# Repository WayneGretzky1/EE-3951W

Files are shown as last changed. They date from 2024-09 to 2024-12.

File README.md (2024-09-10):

# Strain guage

You will be designing and building a weight scale using a pre-built strain gauge bridge as shown in the link below:

Note that this package comes with a circuit board containing a custom load cell amplifier and 24 bit analog to digital converter (ADC). You will NOT be allowed to use this for your project. Instead, you will be reading the strain gauge output with the 10-bit ADC available on the Microchip PIC24FJ64GA002 microcontroller and the weight displayed on an appropriate LCD display. 

_**Detailed Specifications:**_

The system should display the weight of a test weight, in grams, to the nearest gram. The range should be 0-1000 grams. The system should have an auto zero ("tare") button to correct for any offset error. Note that a 10-bit ADC only has 1024 quantization levels so the system cannot correct large offset errors by digital offsets. Power supplies may be batteries, USB power, or wall power - it's your choice. The final system should function independently (not be tethered to a laptop other than possibly for power). More details will be provided in class.

_**The Boring Stuff:**_

1. Since the analog portion of the circuit will be connected to the analog to digital converter on your PIC board, putting the analog circuit in a box is not necessary, but you should plan on having it mounted in a stable fashion to facilitate testing and demonstration, If you do choose to put the circuit in a box, we suggest the  Bud 750-1015 box or equivalent, available from the ECE Depot, but other creative solutions are fine too including 3D printed boxes (there seems to be a competition every semester for who can make the cutest box); that's fine, but don't obsess too much about the box. The whole thing should be reasonable sized (6” on a side or less), if you feel you need to make a bigger board/box, please consult your TA first.

2. Components should be available from Digi-Key (they have the quickest delivery), Mouser Electronics (they are not quite as quick to ship as Digi-Key), or standard items from the ECE Depot. These parts will be ordered through the ECE Depot. A single IC containing the entire project is not permitted. If you wish to incorporate other parts from other suppliers you will be responsible for ordering and paying for them – we will not reimburse groups for these out of pocket expenses.

3. Instructions for Ordering Parts From the ECE Depot  Download Instructions for Ordering Parts From the ECE Depot(These instructions are from Fall 2023 but are still correct).

NOTE: not all parts listed in the supplier catalog are in stock, and ordering out of stock parts may result in substantial delays. Many parts are also surface mount – surface mount parts are often quite small and difficult to solder – if leaded parts (packages with leads like the ones you can plug into a proto-board) are available, they are usually the best choice. We have soldering facilities available in Anderson Labs, the ECE Depot (during the hours the Depot is open), and in the EXCEED lab.

Please designate ONE PERSON form your group to do all of the interfacing with the ECE Depot.

4. The total cost of all parts ordered through the ECE depot should not exceed $50. The circuit board, thermocouple wire, and thermocouple connectors do not need to be included in your budget.

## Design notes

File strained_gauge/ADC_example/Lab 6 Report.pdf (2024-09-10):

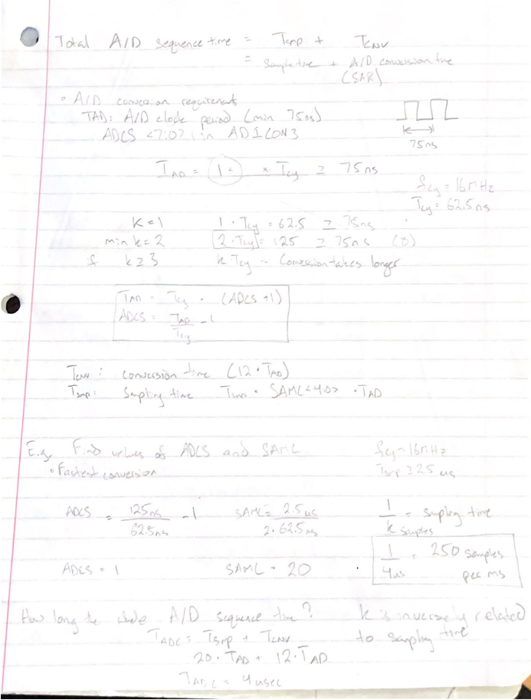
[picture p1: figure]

Max sampling rate is 250 samples per ms, in a sampling time of 4 us, these properties are inversely proportional in that the increase in sampling time (an increase in k) will lead to an decrease in sampling rate and vice versa. When our sample rate increases, we are able to paint a more accurate picture on our display since we are collecting precise values.

Main

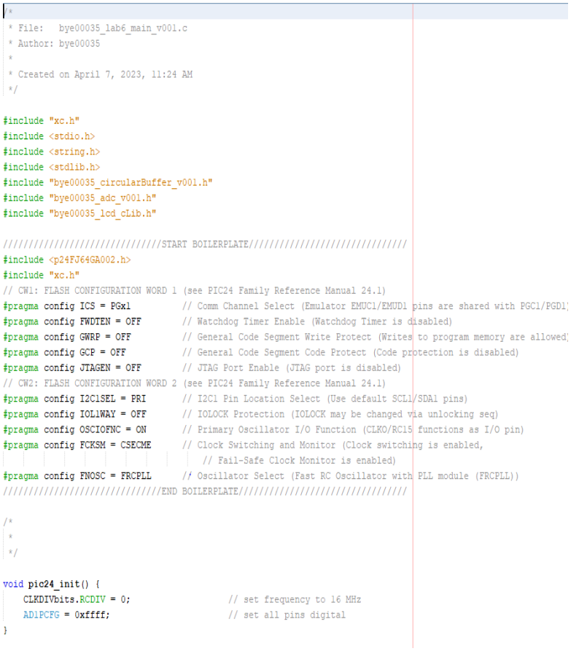
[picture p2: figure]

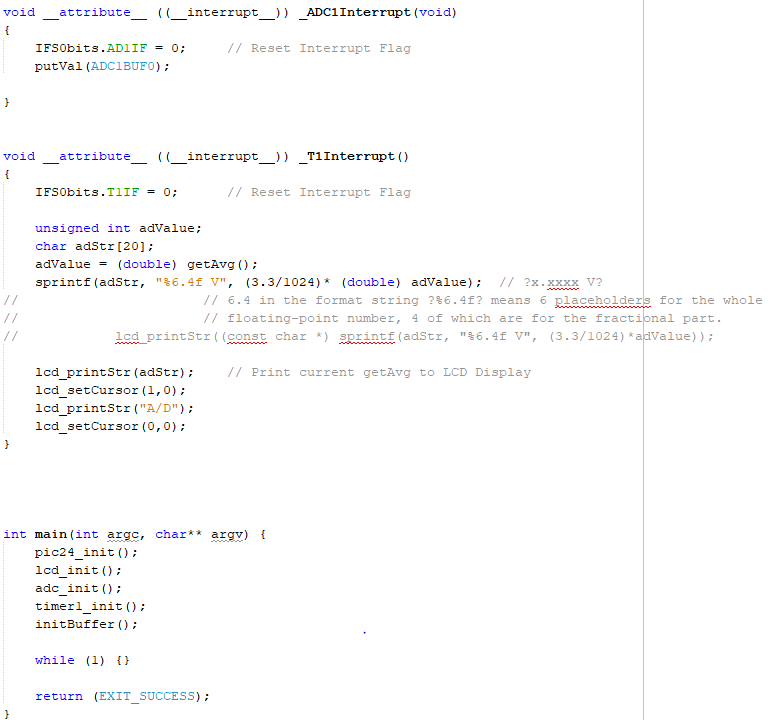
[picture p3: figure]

Header File

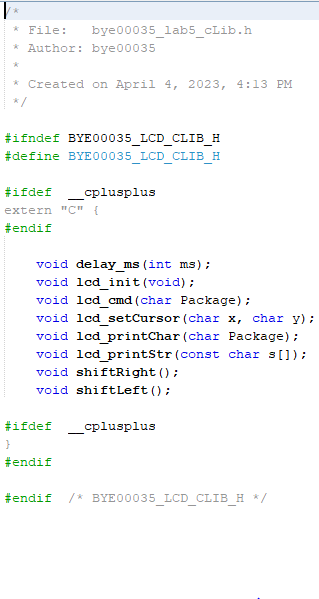
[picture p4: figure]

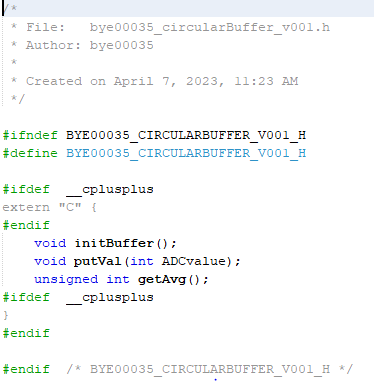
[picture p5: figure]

Library File

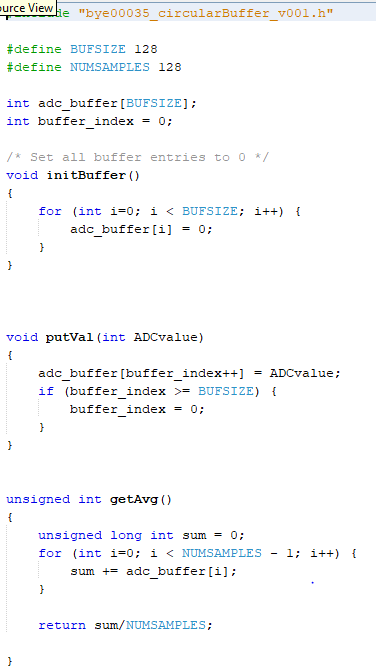
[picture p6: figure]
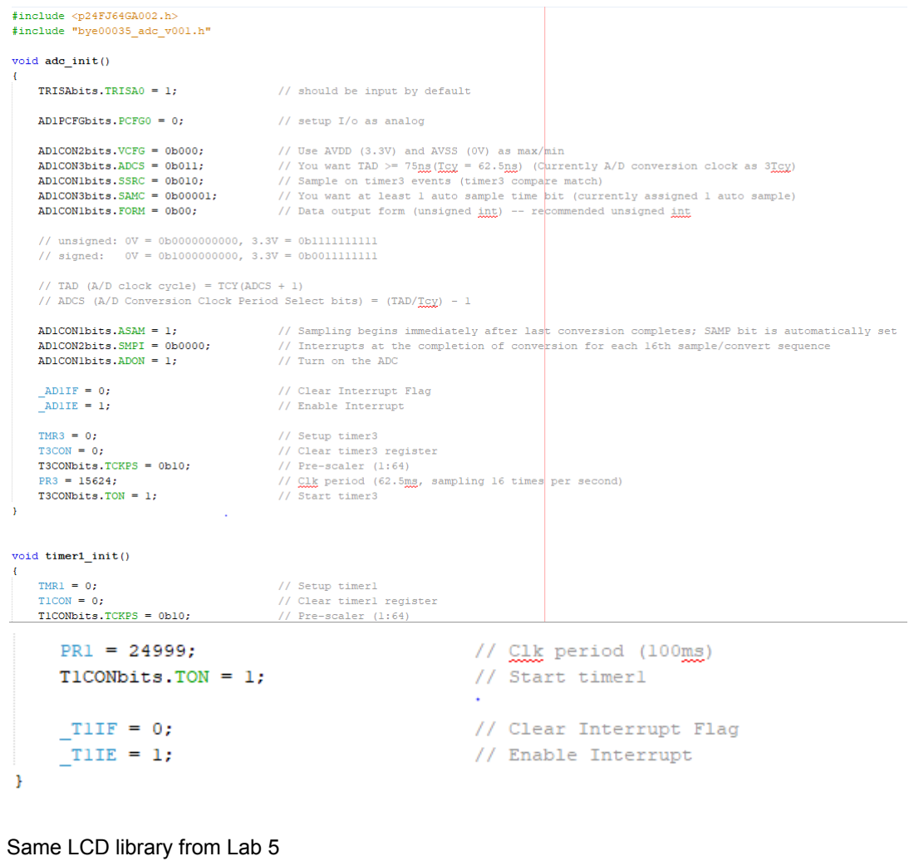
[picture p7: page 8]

Same LCD library from Lab 5

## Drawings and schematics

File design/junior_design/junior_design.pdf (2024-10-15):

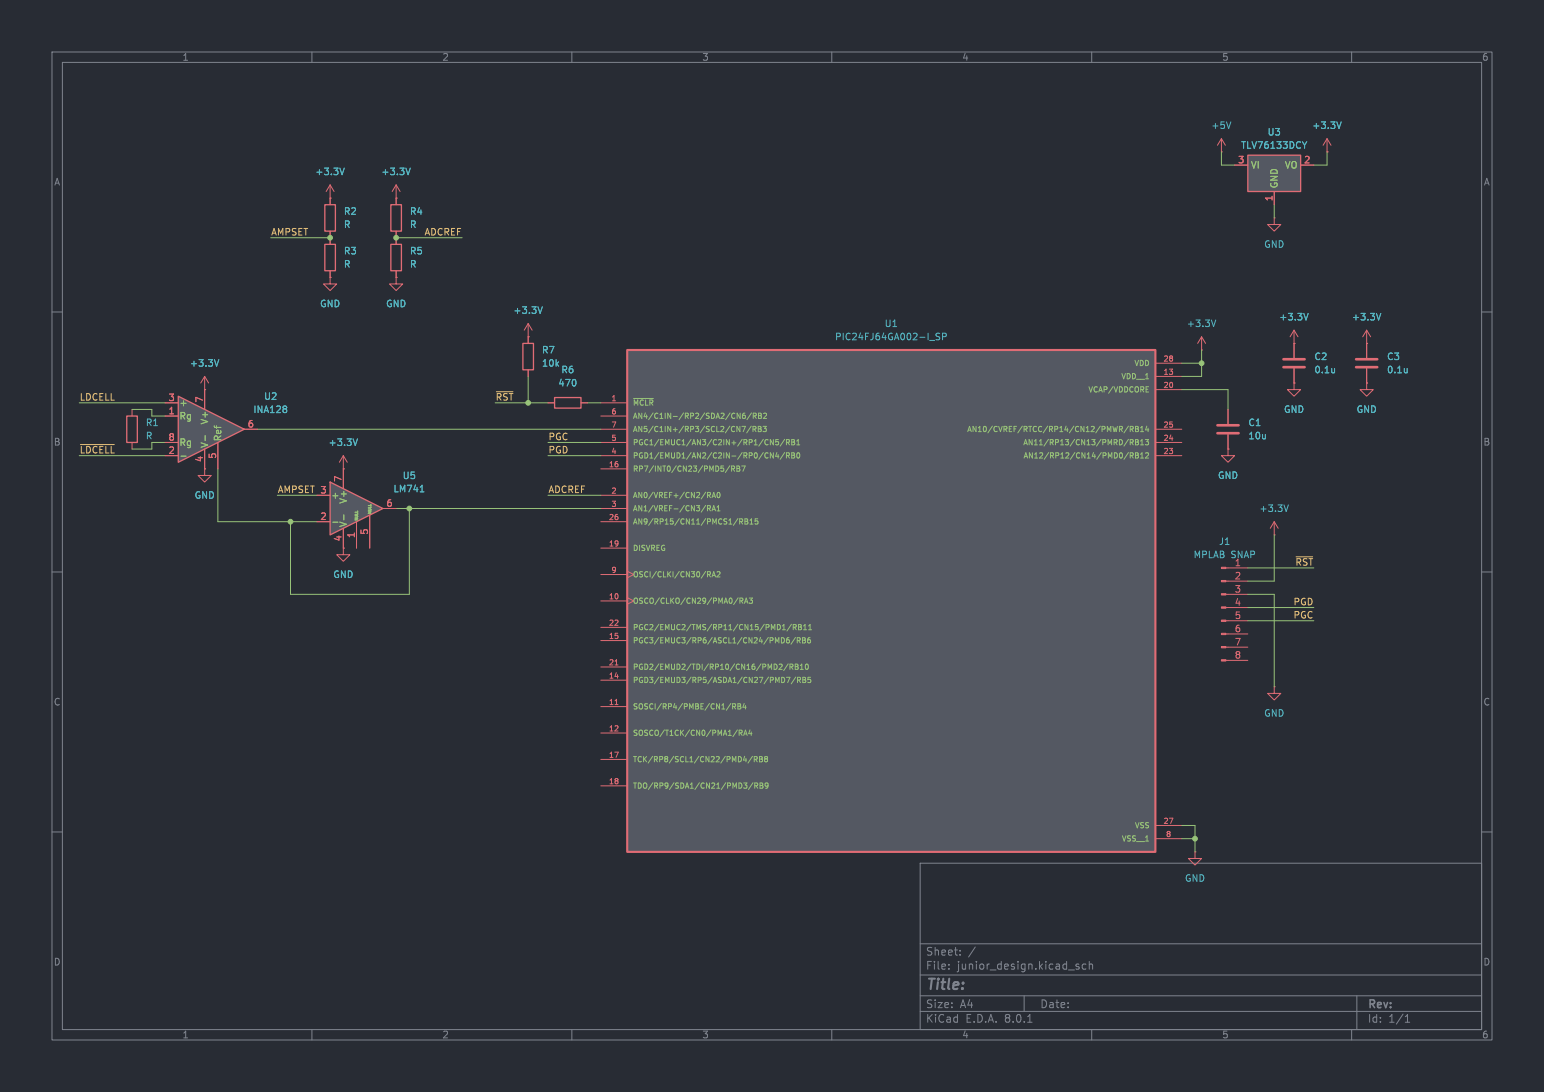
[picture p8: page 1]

Id: 1/1 Title: File: junior_design.kicad_sch Sheet: /

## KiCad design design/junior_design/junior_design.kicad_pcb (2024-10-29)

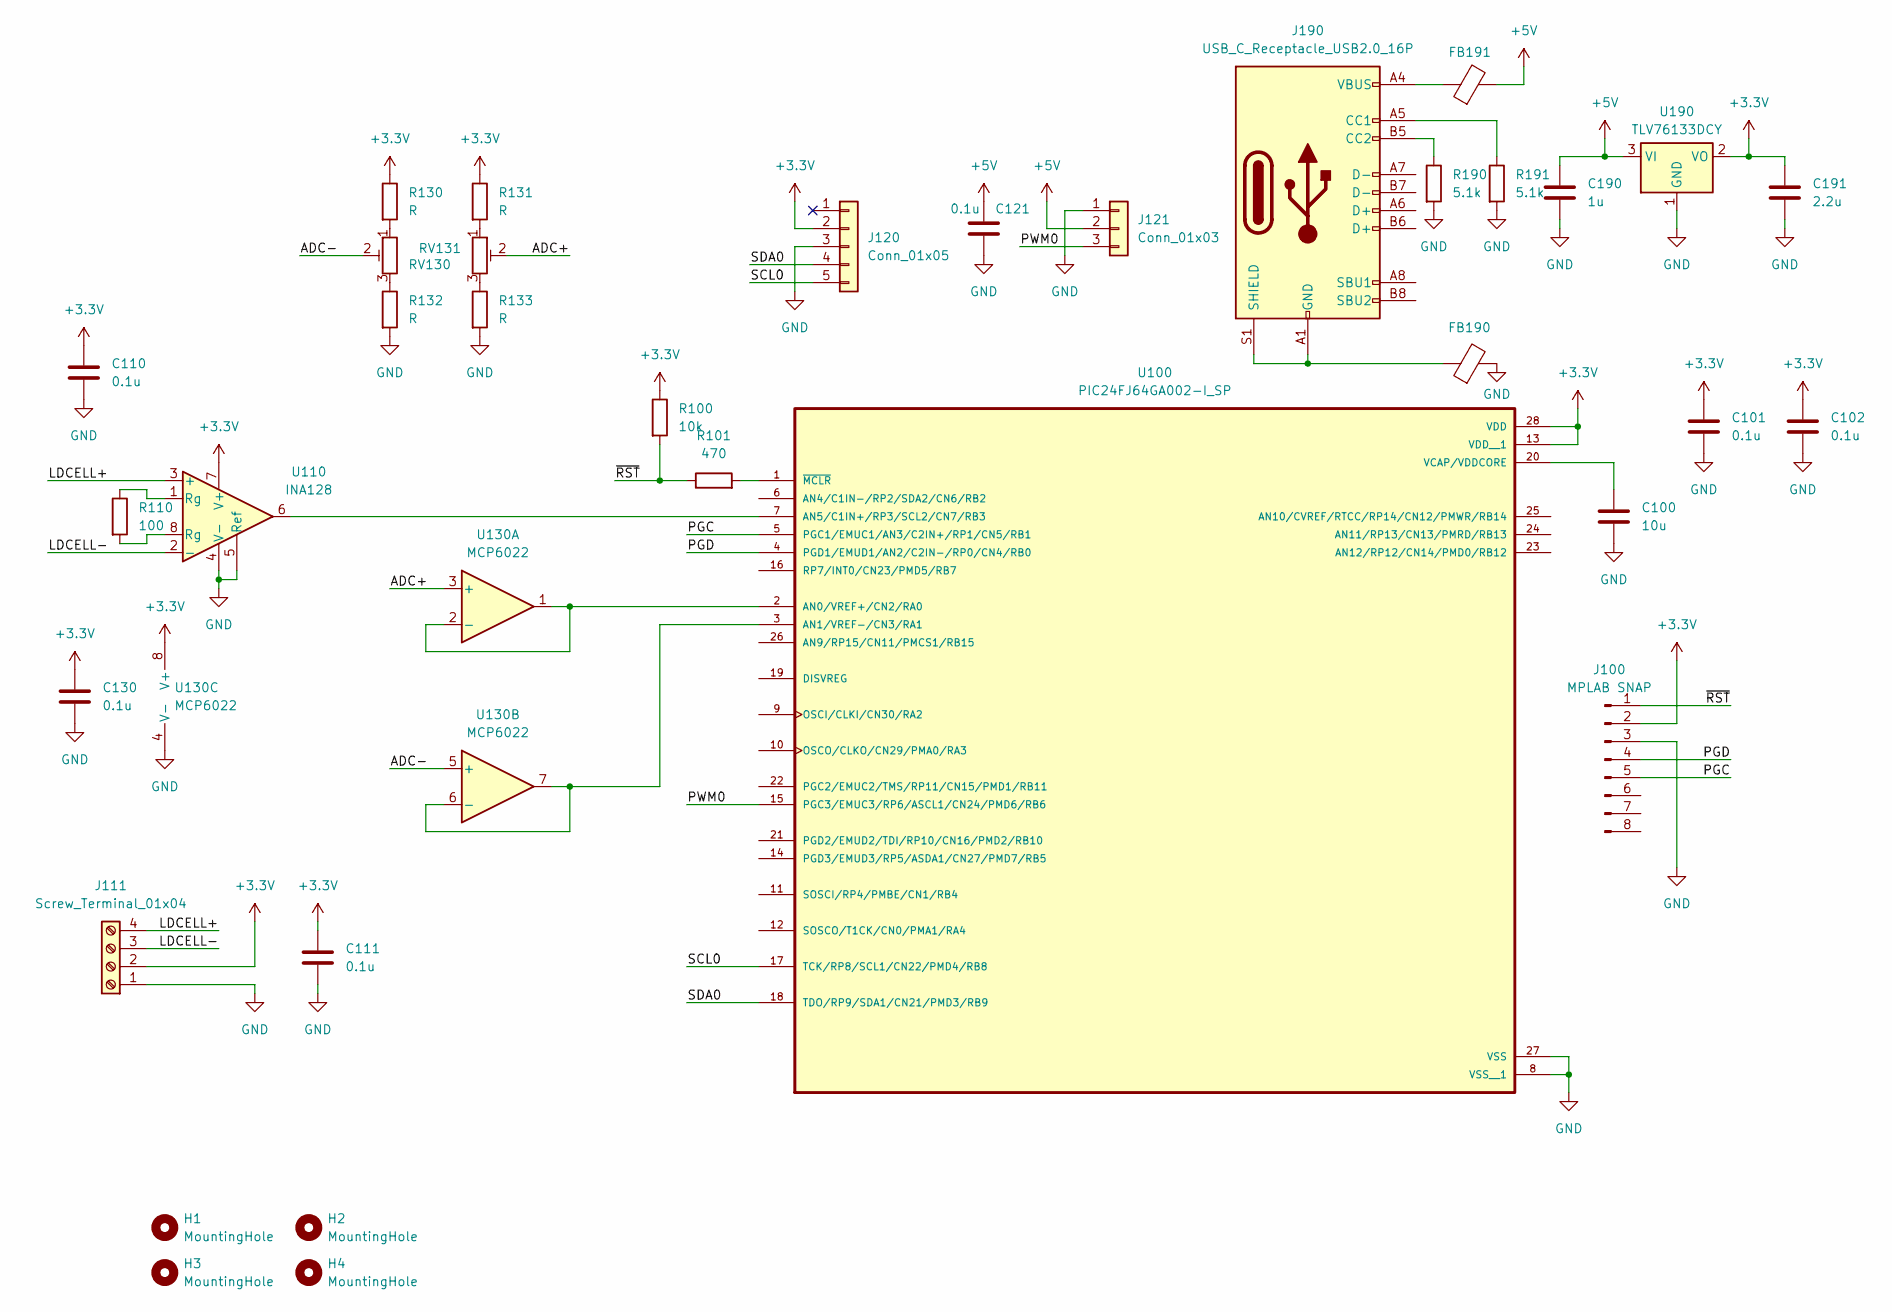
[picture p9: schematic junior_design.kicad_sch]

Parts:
C100: 10u; C_0805_2012Metric_Pad1.18x1.45mm_HandSolder
C101, C102, C110, C111, C121, C130: 0.1u; C_0603_1608Metric_Pad1.08x0.95mm_HandSolder
C190: 1u; C_0603_1608Metric_Pad1.08x0.95mm_HandSolder
C191: 2.2u; C_0603_1608Metric_Pad1.08x0.95mm_HandSolder
FB190, FB191: FerriteBead; L_0603_1608Metric_Pad1.05x0.95mm_HandSolder
H1, H2, H3, H4: MountingHole; MountingHole_2.7mm
J100: MPLAB SNAP; PinHeader_1x08_P2.54mm_Horizontal
J111: Screw_Terminal_01x04; PhoenixContact_MC_1,5_4-G-3.81_1x04_P3.81mm_Horizontal
J120: Conn_01x05; PinHeader_1x05_P2.54mm_Vertical
J121: Conn_01x03; PinHeader_1x03_P2.54mm_Vertical
J190: USB_C_Receptacle_USB2.0_16P; USB_C_Receptacle_GCT_USB4085
R100: 10k; R_0603_1608Metric_Pad0.98x0.95mm_HandSolder
R101: 470; R_0603_1608Metric_Pad0.98x0.95mm_HandSolder
R110: 100; R_0603_1608Metric_Pad0.98x0.95mm_HandSolder
R130, R131, R132, R133: R; R_0603_1608Metric_Pad0.98x0.95mm_HandSolder
R190, R191: 5.1k; R_0603_1608Metric_Pad0.98x0.95mm_HandSolder
RV130, RV131: R_Potentiometer_Trim; Potentiometer_Bourns_3266Y_Vertical
U100: PIC24FJ64GA002-I_SP; DIP-28_W7.62mm
U110: INA128; DIP-8_W7.62mm
U130: MCP6022; DIP-8_W7.62mm
U190: TLV76133DCY; SOT-223-3_TabPin2

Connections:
+3.3V: C101.1, C102.1, C110.1, C111.1, C130.1, C191.1, J100.2, J111.2, J120.2, R100.1, R130.1, R131.1, U100.13 (VDD__1), U100.28 (VDD), U110.7 (V+), U130.8 (V+), U190.2 (VO)
+5V: C121.1, C190.1, FB191.2, J121.2, U190.3 (VI)
/ADC+: RV131.2, U130.3 (+)
/ADC-: RV130.2, U130.5 (+)
/LDCELL+: J111.4, U110.3 (+)
/LDCELL-: J111.3, U110.2 (-)
/PGC: J100.5, U100.5 (PGC1/EMUC1/AN3/C2IN+/RP1/CN5/RB1)
/PGD: J100.4, U100.4 (PGD1/EMUD1/AN2/C2IN-/RP0/CN4/RB0)
/PWM0: J121.3, U100.15 (PGC3/EMUC3/RP6/ASCL1/CN24/PMD6/RB6)
/SCL0: J120.5, U100.17 (TCK/RP8/SCL1/CN22/PMD4/RB8)
/SDA0: J120.4, U100.18 (TDO/RP9/SDA1/CN21/PMD3/RB9)
/~RST: J100.1, R100.2, R101.1
GND: C100.2, C101.2, C102.2, C110.2, C111.2, C121.2, C130.2, C190.2, C191.2, FB190.2, J100.3, J111.1, J120.3, J121.1, R132.2, R133.2, R190.2, R191.2, U100.8 (VSS__1), U100.27 (VSS), U110.4 (V-), U110.5 (Ref), U130.4 (V-), U190.1 (GND)
unnamed: FB191.1, J190.A4 (VBUS), J190.A9 (VBUS), J190.B4 (VBUS), J190.B9 (VBUS)
unnamed: J190.A5 (CC1), R191.1
unnamed: J190.B5 (CC2), R190.1
unnamed: FB190.1, J190.A1 (GND), J190.A12 (GND), J190.B1 (GND), J190.B12 (GND), J190.S1 (SHIELD)
unnamed: R110.1, U110.1 (Rg)
unnamed: R110.2, U110.8 (Rg)
unnamed: R130.2, RV130.1
unnamed: R131.2, RV131.1
unnamed: R132.1, RV130.3
unnamed: R133.1, RV131.3
unnamed: U100.2 (AN0/VREF+/CN2/RA0), U130.1, U130.2 (-)
unnamed: U100.3 (AN1/VREF-/CN3/RA1), U130.6 (-), U130.7
unnamed: U100.7 (AN5/C1IN+/RP3/SCL2/CN7/RB3), U110.6
unnamed: C100.1, U100.20 (VCAP/VDDCORE)
unnamed: R101.2, U100.1 (~MCLR)

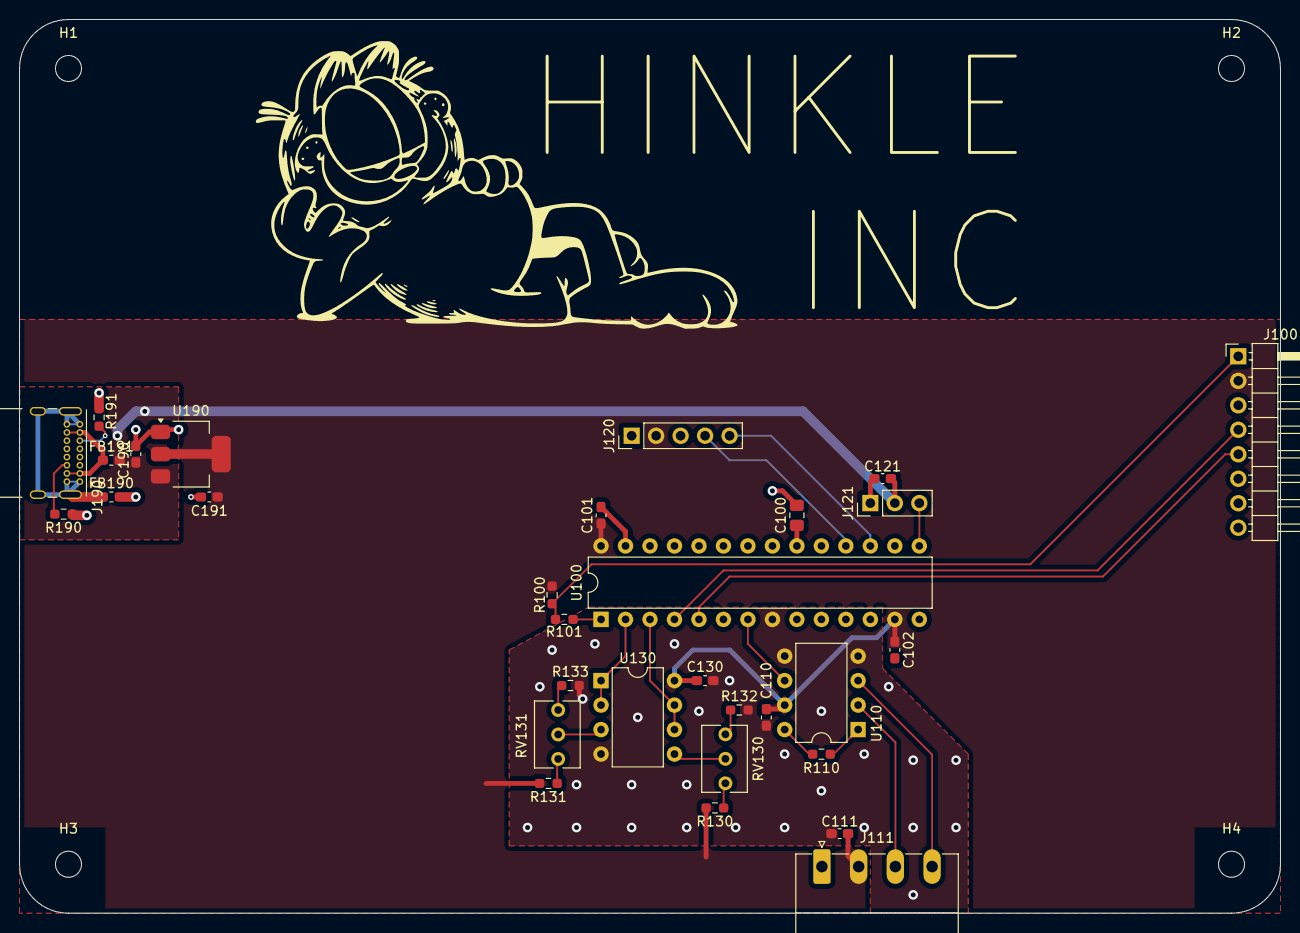
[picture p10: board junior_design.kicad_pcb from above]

Board: 2 copper layers, 130.8 x 92.7 mm, 35 parts (0 on the bottom side), 28 nets.

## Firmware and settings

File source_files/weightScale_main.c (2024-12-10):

/* 
 * File:   bye00035_lab5_main_v001.c
 * Author: brock
 *
 * Created on March 23, 2023, 2:18 PM
 */

#include "xc.h"
#include "../previous_labs/ADC_example_BB/bye00035_adc_v001.h"
#include "../previous_labs/buffer_lib_NT/tonn0030_lab6_bufferLib_v001.h"
#include "../previous_labs/LCD_Lib_NT/tonn0030_lab5_lcdLib_v001.h"
#include "../previous_labs/servo.X/servo_setup.h"
#include "../header_files/data.h"
#include <stdio.h>
#include <string.h>
#include <stdlib.h>

// CW1: FLASH CONFIGURATION WORD 1 (see PIC24 Family Reference Manual 24.1)
#pragma config ICS = PGx1          // Comm Channel Select (Emulator EMUC1/EMUD1 pins are shared with PGC1/PGD1)
#pragma config FWDTEN = OFF        // Watchdog Timer Enable (Watchdog Timer is disabled)
#pragma config GWRP = OFF          // General Code Segment Write Protect (Writes to program memory are allowed)
#pragma config GCP = OFF           // General Code Segment Code Protect (Code protection is disabled)
#pragma config JTAGEN = OFF        // JTAG Port Enable (JTAG port is disabled)


// CW2: FLASH CONFIGURATION WORD 2 (see PIC24 Family Reference Manual 24.1)
#pragma config I2C1SEL = PRI       // I2C1 Pin Location Select (Use default SCL1/SDA1 pins)
#pragma config IOL1WAY = OFF       // IOLOCK Protection (IOLOCK may be changed via unlocking seq)
#pragma config OSCIOFNC = ON       // Primary Oscillator I/O Function (CLKO/RC15 functions as I/O pin)
#pragma config FCKSM = CSECME      // Clock Switching and Monitor (Clock switching is enabled, 
// Fail-Safe Clock Monitor is enabled)
#pragma config FNOSC = FRCPLL      // Oscillator Select (Fast RC Oscillator with PLL module (FRCPLL))

/*
 * In this lab, your objective is to create a 
 * fully functional library for the 3.3V Small LCD display by SwitchScience.  
 * This library should consist of an initialization function, 
 * cursor location set function, and a string writing function.  
 * Together you will use these functions to create and animate a message on the LCD display.
 */


volatile int test;
volatile char time_to_refresh = 0;
volatile uint16_t ADCValue = 0;
volatile int *ADC16Ptr;
void __attribute__((interrupt, auto_psv)) _ADC1Interrupt()
{
    for (int count = 0; count < 8; count++) // average the 16 ADC value
        {
            putVal(LUT[*ADC16Ptr]);
            ADC16Ptr++;
        }
    
    time_to_refresh = 1;
    ADC16Ptr = &ADC1BUF0; // initialize ADC1BUF pointer
    IFS0bits.AD1IF = 0; // clear ADC interrupt flag
}


void setup()
{
    initBuffer();
    adc_init();
    lcd_init();
    servoSetup();
    lcd_moveCurser(0,0);
    TMR3 = 0;
    T3CON = 0;
    T3CONbits.TCKPS = 0b10;
    PR3 = 31250 - 1;
    T3CONbits.TON = 1;
}

// use shift left command for part 2
int main(int argc, char** argv) {
    char adStr[20];
    setup();
    //uint8_t waitCounter = 0;
    int weight = getAvg();
    while(1){
        if(time_to_refresh){
            weight = getAvg();
            setScaleServo(weight);
            sprintf(adStr, "%d", weight);
            lcd_clear();            
            delayMs(1);
            lcd_moveCurser(0,0);
            lcd_printStr(adStr);
            lcd_moveCurser(0,4);
            lcd_printChar('g');
            time_to_refresh = 0;
            AD1CON1bits.ASAM = 1; // auto start sampling for 31Tad
        }
    }

    return (0);
}

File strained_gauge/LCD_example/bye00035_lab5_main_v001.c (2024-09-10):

/* 
 * File:   bye00035_lab5_main_v001.c
 * Author: brock
 *
 * Created on March 23, 2023, 2:18 PM
 */

#include "xc.h"
#include <stdio.h>
#include <stdlib.h>

/*
 * In this lab, your objective is to create a 
 * fully functional library for the 3.3V Small LCD display by SwitchScience.  
 * This library should consist of an initialization function, 
 * cursor location set function, and a string writing function.  
 * Together you will use these functions to create and animate a message on the LCD display.
 */



void pic24_init() {
    CLKDIVbits.RCDIV = 0;                   // set frequency to 16 MHz
    AD1PCFG = 0xffff;                       // set all pins digital
    TRISA = 0b1111111111111110;             // set RA0 to output
}

void delay_ms(int ms){
    while(ms-- > 0){
        asm("repeat #15998");
        asm("nop");
    }
}


/**
 * This function should implement the complete sequence of lcd_cmd() 
 * writes and delays needed to initialize the LCD.
 * Make sure the contrast is adjustable (by a global variable, argument, or compiler definition).
 */
void lcd_init(void) {
    I2C2BRG = 0x9D;                         // set to a clock frequency of 100 kHz
    IFS3bits.MI2C2IF = 0;                   // Clear interrupt flag
    I2C2CONbits.I2CEN = 1;                  // Enable I2C Mode
    
    delay_ms(40);
    
    lcd_cmd(0b00111000);                    // function set
    lcd_cmd(0b00111001);                    // function set, advance instruction mode
    lcd_cmd(0b00010100);                    // interval set
    lcd_cmd(0b01110000);                    // contrast Low
    lcd_cmd(0b01011110);                    
    lcd_cmd(0b01101100);                    // follower control

    delay_ms(200);
    
    lcd_cmd(0b00111000);                    // function set
    lcd_cmd(0b00001100);                    // Display on
    lcd_cmd(0b00000001);                    // Clear Display
    
    delay_ms(2);
}


/**
 * This function should take a single byte/char command and write it out the I2C bus.  
 * The complete packet should consist of a START bit, address with R/nW byte, 
 * control byte, command/data byte, and STOP bit.
 * @param Package
 */
void lcd_cmd(char Package) {
    // The MI2C2IF requires a software reset before every send. 
    // The MI2C2IF can be triggered by many different events, not just by the acknowledgement (refer to the family datasheet). 
    // Additionally, this is not the only bit that you can wait on. 
    // Make sure you check what triggers whatever bit you use and whether or not it requires a software reset.
    
    // Send START
    IFS3bits.MI2C2IF = 0;                   // Refer to note above
    I2C2CONbits.SEN = 1;                    // Initiate Start condition
    
    delay_ms(2);
    while (I2C2CONbits.SEN == 1);           // SEN will clear when Start Bit is complete
    
    // Send Address and Write Command
    IFS3bits.MI2C2IF = 0;
    I2C2TRN = 0b01111100;                   // 8-bits consisting of the slave address and the R/nW bit
    
    // Send high byte (always 0x00)
    delay_ms(2);

    while (IFS3bits.MI2C2IF == 0);
    IFS3bits.MI2C2IF = 0;
    I2C2TRN = 0b00000000;                   // 8-bits consisting of control byte
    
    // Send Package
    delay_ms(2);
    while (IFS3bits.MI2C2IF == 0);
    IFS3bits.MI2C2IF = 0;
    I2C2TRN = Package;                      // 8-bits consisting of the data byte
    
    // Send STOP
    delay_ms(2);
    while (IFS3bits.MI2C2IF == 0);
    IFS3bits.MI2C2IF = 0;
    
    I2C2CONbits.PEN = 1;                    // PEN will clear when Stop bit is complete
    while (I2C2CONbits.PEN == 1);
}


/**
 * This function should consist of a single lcd_cmd() statement with a 
 * masked and calculated command to set the Cursor to row y, column x.
 * @param x
 * @param y
 */
void lcd_setCursor(char x, char y)
{
    
}


/**
 * This is really only a test function to verify the LCD operation.  
 * It should consist of a single I2C packet (START, Address, control, data, STOP).  
 * Unlike the lcd_cmd() function it will have different values for RS and CO bit values.
 * @param Package
 */
void lcd_printChar(char Package) {
    
    IFS3bits.MI2C2IF = 0;                   // Refer to note above
    I2C2CONbits.SEN = 1;                    // Initiate Start condition
    
    delay_ms(2);
    while (I2C2CONbits.SEN == 1);
    IFS3bits.MI2C2IF = 0;
    I2C2TRN = 0b01111100;                   // 8-bits consisting of the slave address and the R/nW bit

    delay_ms(2);    
    while (IFS3bits.MI2C2IF == 0);
    IFS3bits.MI2C2IF = 0;
    I2C2TRN = 0b01000000;                   // 8-bits consisting of control byte /w RS=1
    
    delay_ms(2);
    while (IFS3bits.MI2C2IF == 0);
    IFS3bits.MI2C2IF = 0;
    I2C2TRN = Package;                      // 8-bits consisting of the data byte
   
    delay_ms(2);
    while (IFS3bits.MI2C2IF == 0);
    IFS3bits.MI2C2IF = 0;
    
    I2C2CONbits.PEN = 1;                    // PEN will clear when Stop bit is complete
    while (I2C2CONbits.PEN == 1);
}


int main(int argc, char** argv) {
    pic24_init();                           // set clock to 16MHz and all pins digital
    lcd_init();                             // initialize the LCD screen for future use
    
    lcd_printChar('a');              // print the char 'a' to the screen
    //0b01000001
    while(1);
    return (0);
}

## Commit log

2024-09-17 Added simple main and adc lib files to project
2024-09-24 added working pin select and reference voltages
2024-10-08 Added LCD display code and ADC is working
2024-10-15 add kicad design to repo
    [junior_design.kicad_pcb, junior_design.kicad_sch]
2024-10-15 add pcb
    [junior_design.kicad_pcb, junior_design.kicad_sch]
2024-10-15 Started PCB layout
    [junior_design.kicad_pcb, junior_design.kicad_sch]
2024-10-15 Finish routing PCB
    [junior_design.kicad_pcb, junior_design.kicad_sch]
2024-10-17 add ferrite beads to usb-c port
    [junior_design.kicad_pcb, junior_design.kicad_sch]
2024-11-05 Got the ADC working
2024-11-20 Add servo files
2024-12-03 Fixed ADC, and added working servo code
    [bye00035_adc_v001.c, servo_setup.c, weightScale_main.c]
